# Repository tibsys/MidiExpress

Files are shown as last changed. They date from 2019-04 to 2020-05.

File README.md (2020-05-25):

# A MIDI-USB expression pedal for 25 Euros

MIDIExpress is a MIDI-PC interface originaly designed to connect an expression pedal to a **PC** or an **iPad** using USB.

## Current version

**Version 1.0**

## Licensing

The design and source codes are provided freely under a closed licence. It makes you able to implement the whole project for your own usage but not to sell it.

If you want to use it in a commercial project please contact me at tristan@alefbet.net.

## IMPORTANT: USB device PID and VID

The current values for PID and VID are random values (PID=0x2340, VID=Ox8030). They are not registered with USB-FI. You may override these values but your are not allowed to sell a product using these ID.

## Cost

_Prices include VAT 20%_

| Part | Unit (€) | Qty | Sub-total (€) |
|---|---|-----|---|
| M-AUDIO EX-P | 16.00 | 1 | 16.00 |
| ATmega 32u4 | 4.00 | 1 | 4.00 |
| USB cable (1) | 2.60 | 1 | 2.60 |
| USB connector (2) | 1.70 | 1 | 1.70 |
| Small parts | 0.50 | - | 0.50 |
|-------------------|----------|-----|---------------|
| Total | 24.80 | 1 | 24.80 |

(1): Bare USB cable
(2): USB Micro B connector

If you dont' want to do it yourself, please contact me at tristan@alefbet.net

## Requirements

- provide PC connectivity to an expression with a Jack connector
- ensure compatibility with all DAWs and MIDI controllers

## Presentation

The project consists in an electronic device which is responsible of converting the pedal into a MIDI device. 

## Licenses and credits

- Arduino schemas made with [Fritzing](http://fritzing.org/).
- Configuration software made with Qt 5.12.0 community edition.

# Do It Yourself

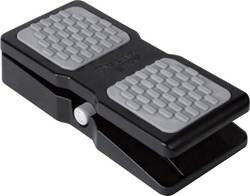
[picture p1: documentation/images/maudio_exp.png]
USB-MIDI expression pedal based on M-AUDIO EX-P


The USB-MIDI expression pedal is based on an M-AUDIO EX-P expression pedal (around 16 Euros on Amazon). The electronic device (see Jack-USB section) is embedded into the pedal and the original Jack cable is replaced with a USB cable.

This device is powered by USB.

## Architecture

> The original M-Audio EX-P pedal contains a switch for polarity inversion and a potentiometer for the sensitivity.

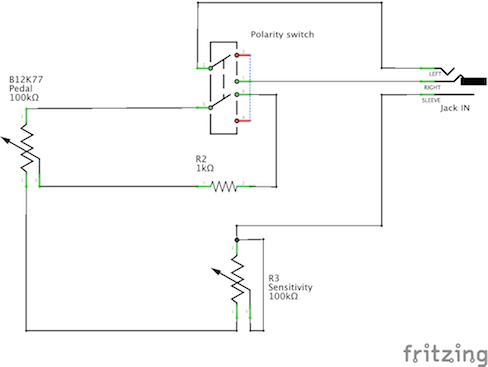
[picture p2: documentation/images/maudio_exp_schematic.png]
Original M-Audio EX-P pedal schematic


> We disabled the polarity switch and kept the sensitivity potentiometer to give manual control on the expression range.

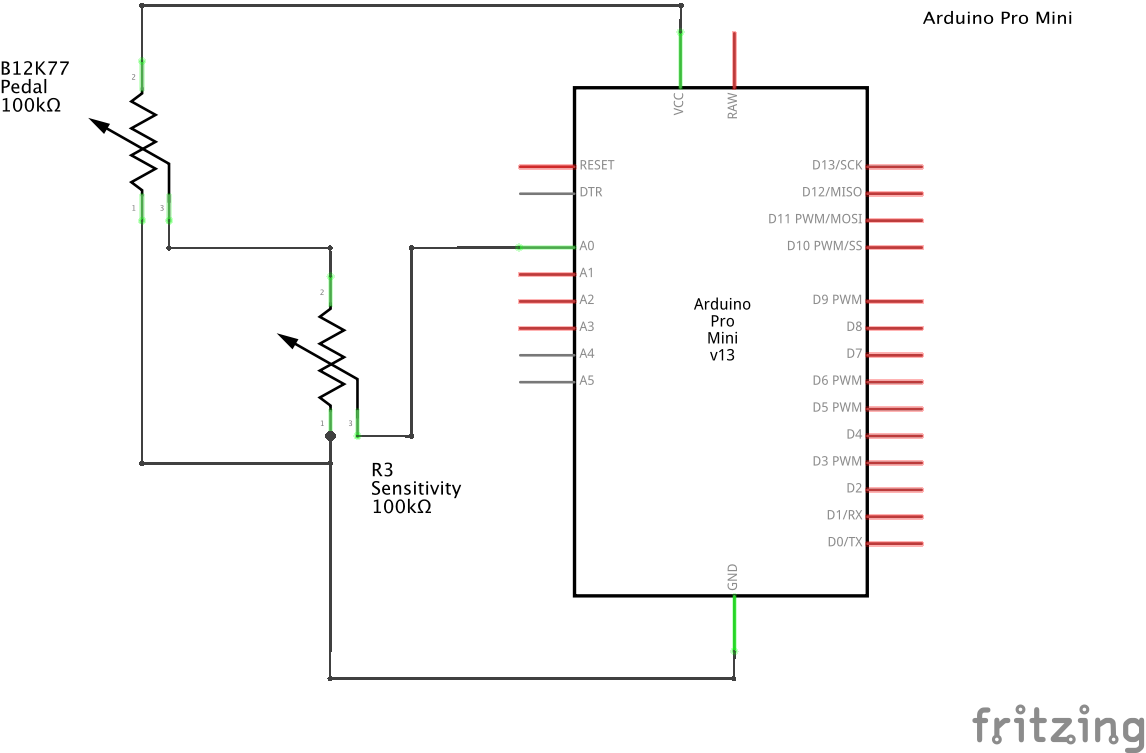
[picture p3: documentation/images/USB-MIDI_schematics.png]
Modified M-Audio EX-P pedal schematic


## Protocol

The pedal does not use any specific channel, it communicates with the *ALL* channel (1-16).

**Pedal -> DAW**

The pedal only sends *Foot Controller* Control Change (MIDI CC 4) on *ALL* channel. Values are between 0 (pedal open) and 128 (pedal closed).

**DAW -> Pedal**

All messages are ignored.

## Mounting procedure

> Before mounting the pedal you'll have to flash the Arduino program. (See Arduino folder). 

If you want the device to have a more friendly name than *Arduino Leonardo*, install the board description files into Arduino IDE (see support folder) and use the *MIDI Expression pedal* board instead of *Arduino Leonardo*.

> All the soldering should be done on the top side of the Arduino in order to be able to stick it to the bottom of the pedal.

- Open the M-AUDIO pedal by unscrewing all screws

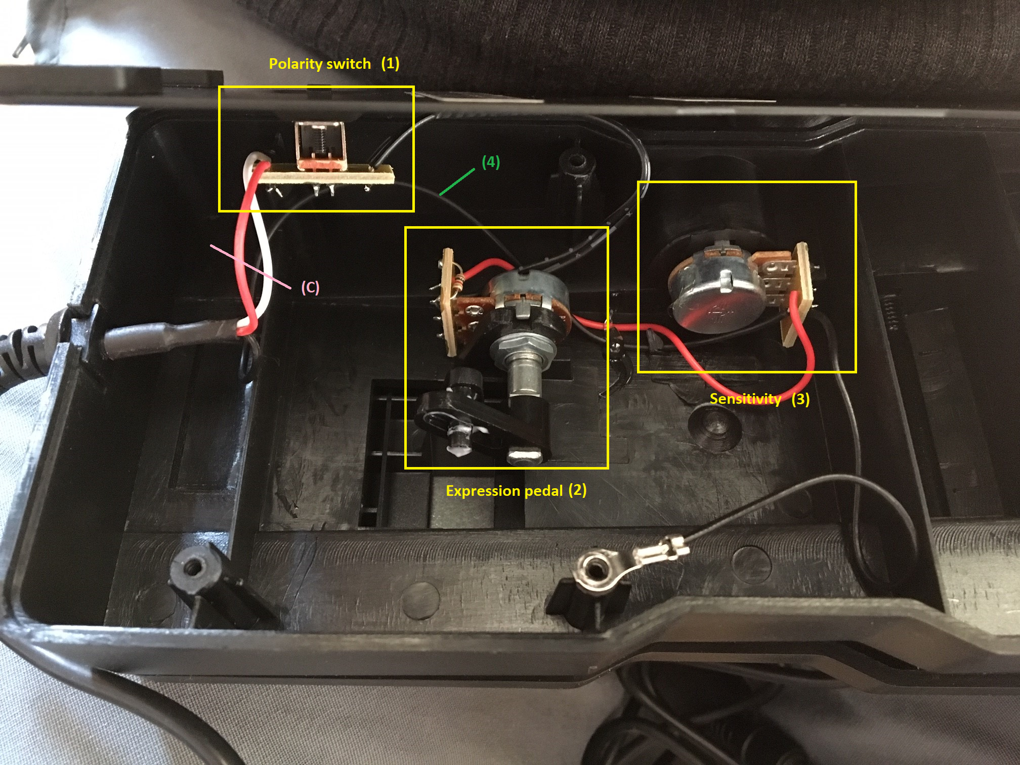
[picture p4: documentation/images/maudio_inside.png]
Inside not-modified M-AUDIO EX-P pedal


- Desolder the polarity switch wires (1)
- Cut the JACK cable and remove the grommet, we will reuse it later

Get the grommet

- Solder the black wire (4) of sensitivity potentiometer (3) to Arduino GND
- Solder the black wire (5) of expression pedal potentiometer (2) to Arduino VCC
> The wire is connected to the input of the potentiometer
- Solder the black wire (6) of expression pedal potentiometer (2) to Arduino A0 
> The wire is connected to the output of the potentiometer

- Insert the bare USB cable into the grommet and solder the Micro USB connector
- Add some black tape on the USB cable in order to fix it with the grommet (the tape sticky side on the cable, the cable will adhere to the grommet by friction)
- Insert the Micro USB connector into the Arduino USB port
- Stick the Arduino board to the bottom of the pedal with some good melted glue (and let it dry)

After sticking the Arduino

- Test the pedal with you DAW

> The pedal in high position

Pedal test

> The pedal in low position

Pedal test

- Close the M-AUDIO pedal.

- You're done

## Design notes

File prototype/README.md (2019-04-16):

# prototype

This sub-tree contains the projects created for the prototype. It will be removed at the end.

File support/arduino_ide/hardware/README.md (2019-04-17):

## Arduino board definition

Move this subdirectory "midiexpress" to the Arduino directory under hardware subdir.

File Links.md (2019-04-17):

# How to

This page gathers some helpful documentation related to AVR, MIDI and enclosures.

## MIDI how tos
- https://www.arduino.cc/en/Tutorial/MidiDevice

## Flash the firwmare into an Arduino Nano
- https://skyduino.wordpress.com/2011/12/02/tutoriel-avrdude-en-ligne-de-commande/
- https://tutorial.cytron.io/2015/02/05/using-avr-usbasp-to-program-arduino/
- http://www.hmangas.com/Electronica/Datasheets/USBasp/AVR-USBasp%20User%20Manual.pdf
- https://www.fischl.de/usbasp/
- avrdude -v -pm328p -cavrisp -b19200 -P/dev/cu.usbserial-A603UXCD -D -Uflash:w:/Users/tristan/Downloads/MidiShield1.hex
- avrdude -v -p m328p -c usbasp -e -b 19200 -U flash:w:/Users/tristan/Downloads/MidiShield1.hex
- https://tosiek.pl/usbasp-v2-0-warning-cannot-set-sck-period/
- https://github.com/obdev/v-usb
- http://ww1.microchip.com/downloads/en/DeviceDoc/ATmega48A-PA-88A-PA-168A-PA-328-P-DS-DS40002061A.pdf

## USB 
- https://codeandlife.com/2017/09/17/5-usb-midi-adapter-with-atmega32u4/
- http://liveelectronics.musinou.net/MIDIdeviceName.php
- http://pid.codes

## A étudier
- http://codeandlife.com/2017/09/17/5-usb-midi-adapter-with-atmega32u4/#more-2071

## Fasteners
- https://docs-emea.rs-online.com/webdocs/0314/0900766b803148ae.pdf

## Grommets
- https://fr.rs-online.com/web/p/passe-cables-en-caoutchouc/1879605/

## Cables and connectors
- [Bare USB-A, 5.26 Euros](https://fr.rs-online.com/web/p/cables-usb/3248362/)
- [USB-A to Mini-B, 2.60 Euros](https://www.amazon.fr/Vitesse-Broches-Alimentation-Donn%C3%A9es-Cordon/dp/B00L365PY6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)
- [Micro-B Connector, 1.38 Euros](https://fr.rs-online.com/web/p/connecteurs-micro-usb/1360889/)
- [Micro-B shield, 0.285 Euros](https://fr.rs-online.com/web/p/accessoires-de-connecteur-usb/1362300/)
- [USB-A to Mini-B, 3.60 Euros](https://fr.rs-online.com/web/p/products/1216571/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ôle_De_Process-_-Boutons-Poussoirs_And_Voyant_Lumineux_Et_Boîtes_À%C2%A0Boutons_Industriels%7CBoîtes_À%C2%A0Boutons_Équipées-_-PRODUCT_GROUP&matchtype=&pla-458695438936&gclid=EAIaIQobChMI7JeMr4jS4QIVRPhRCh3LxATJEAQYAyABEgKSVPD_BwE&gclsrc=aw.ds)
- [USB-A to Micro-B, 4.80 Euros](https://fr.rs-online.com/web/p/cables-usb/1828496/)

## AVR how tos
- https://maker.pro/custom/tutorial/how-to-take-analog-readings-with-an-avr-microcontroller

## Extra documentation
- https://www.instructables.com/id/Arduino-USB-MIDI-Interface/
- http://www.takachi-enclosure.com/data/c16-17/MX.pdf
- http://www.takachi-enclosure.com/data/c16-17/LCS.pdf
- https://fr.farnell.com/lumberg/klb-3/embase-femelle-chassis-6-35mm/dp/1217017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|pcrid|80993875142|&CAWELAID=120185620000056177&CAGPSPN=pla&CAAGID=13038046742&CMP=KNC-GFR-GEN-SHOPPING-1217017&CATCI=pla-134775292622
- http://www.takachi-enclosure.com/data/c16-17/2017vol3_21-23.pdf
- http://www.takachi-enclosure.com/data/c16-17/SU.pdf
- http://www.takachi-enclosure.com/data/c16-17/SW.pdf
- https://www.astuces-pratiques.fr/electronique/comment-brancher-un-potentiometre
- https://components101.com/sites/default/files/component_pin/potentiometer-pinout.png

## Notes
- M-Audio EX P USB cable is 1/4"
- M-Audio EX P potentiometer is 10k linear

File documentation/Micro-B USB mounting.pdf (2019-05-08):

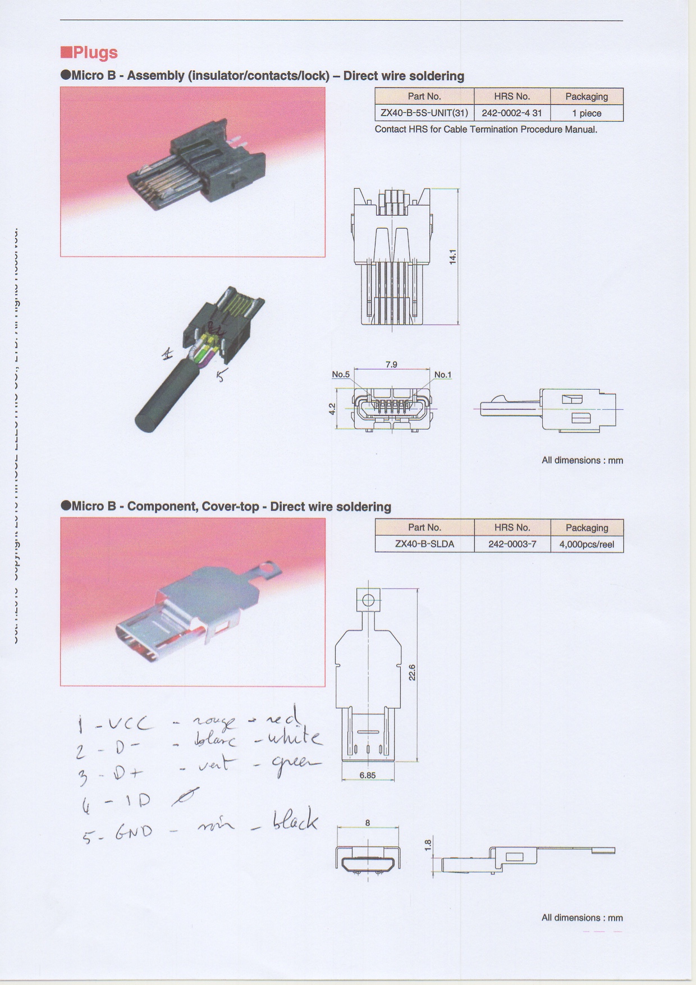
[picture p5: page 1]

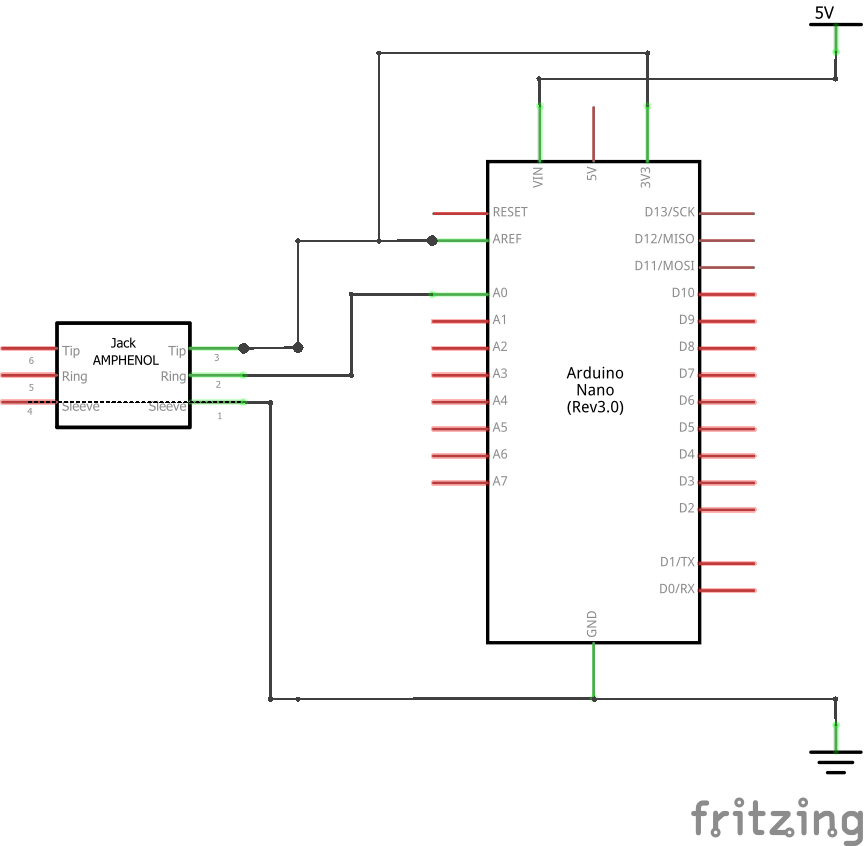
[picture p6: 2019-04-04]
documentation/images/board_schematics.png

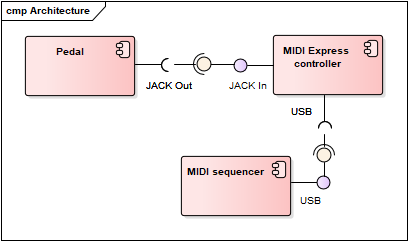
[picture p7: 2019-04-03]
documentation/images/architecture.png

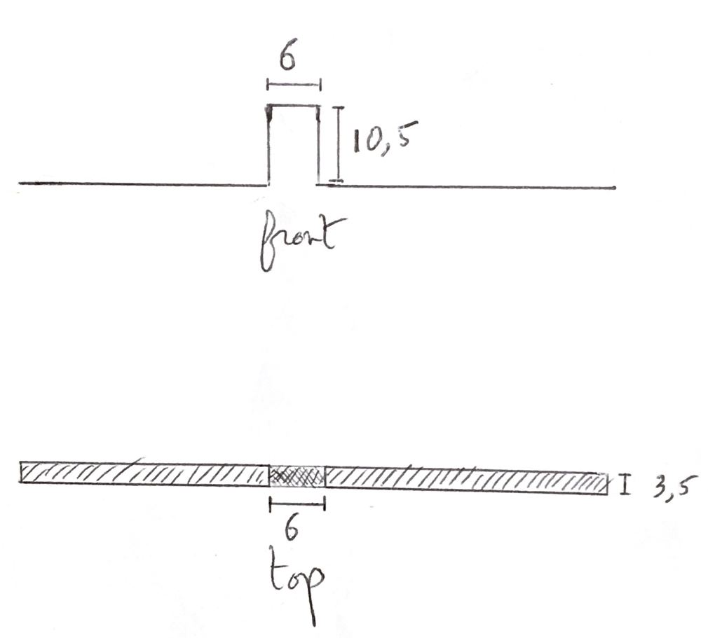
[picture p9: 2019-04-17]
documentation/images/maudio_enclosure.png

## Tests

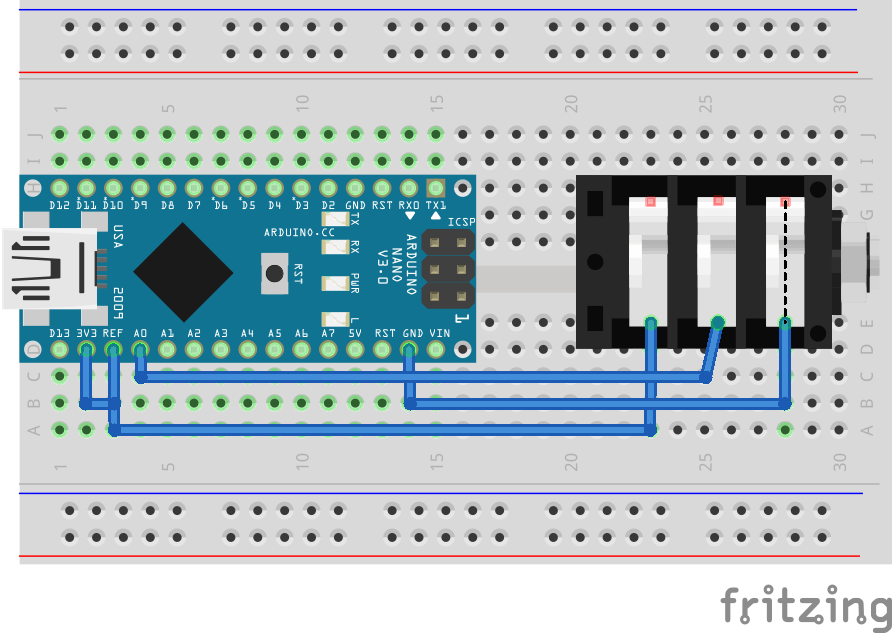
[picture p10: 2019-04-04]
documentation/images/test_board.png

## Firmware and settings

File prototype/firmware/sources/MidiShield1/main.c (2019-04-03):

/* Name: main.c
 * MIDI CONVERTER
 *
 * MOCO: Midi Output Converter
 * MICO: Midi Input Converter
 *
 * (C) 2010 by morecat_lab
 */



#include <string.h>
#include <avr/io.h>
#include <avr/interrupt.h>
#include <avr/pgmspace.h>
#include <avr/wdt.h>

#include "usbdrv/usbdrv.h"
#include "usbdrv/oddebug.h"

extern void parseUSBMidiMessage(uchar *, uchar);
extern uchar parseSerialMidiMessage(uchar);

#define setPortBit0(port, bit) *(port) &= ~_BV(bit);
#define setPortBit1(port, bit) *(port) |= _BV(bit);
#define flipPortBit(port, bit) (*(port) ^= _BV(bit))
#define setPortBit(port, bit, val) { \
    if ((val) == 0) { setPortBit0((port), (bit)); } else	\
      { setPortBit1((port), (bit)); }				\
}

/* debugging LED */
#ifdef ARDUINO
#define LED_OFF  { PORTB &= ~0x20; }
#define LED_ON   { PORTB |=  0x20; }
#define FLIP_LED { PORTB ^=  0x20; }
#else
#define LED_OFF  { PORTB &= ~0x01; }
#define LED_ON   { PORTB |=  0x01; }
#define FLIP_LED { PORTB ^=  0x01; }
#endif

#define RECEIVER
#define TRANSMITTER

/*
 PORT ASSIGN
 PD0: RxD (Serial MIDI)
 PD1: TxD (Serial MIDI)
 PD2: USB D+
 PD3: USB D-

 PD5: LED Monitor

 */

#define HW_CDC_BULK_OUT_SIZE     8
#define HW_CDC_BULK_IN_SIZE      8

#define	TRUE			1
#define	FALSE			0

enum {
    SEND_ENCAPSULATED_COMMAND = 0,
    GET_ENCAPSULATED_RESPONSE,
    SET_COMM_FEATURE,
    GET_COMM_FEATURE,
    CLEAR_COMM_FEATURE,
    SET_LINE_CODING = 0x20,
    GET_LINE_CODING,
    SET_CONTROL_LINE_STATE,
    SEND_BREAK
};

// This deviceDescrMIDI[] is based on 
// http://www.usb.org/developers/devclass_docs/midi10.pdf
// Appendix B. Example: Simple MIDI Adapter (Informative)

// B.1 Device Descriptor
static PROGMEM char deviceDescrMIDI[] = {	/* USB device descriptor */
  18,			/* sizeof(usbDescriptorDevice): length of descriptor in bytes */
  USBDESCR_DEVICE,	/* descriptor type */
  0x10, 0x01,		/* USB version supported */
  0,			/* device class: defined at interface level */
  0,			/* subclass */
  0,			/* protocol */
  8,			/* max packet size */
  USB_CFG_VENDOR_ID,	/* 2 bytes */
  USB_CFG_DEVICE_ID,	/* 2 bytes */
  USB_CFG_DEVICE_VERSION,	/* 2 bytes */
  1,			/* manufacturer string index */
  2,			/* product string index */
  0,			/* serial number string index */
  1,			/* number of configurations */
};

// B.2 Configuration Descriptor
static PROGMEM char configDescrMIDI[] = { /* USB configuration descriptor */
  9,	   /* sizeof(usbDescrConfig): length of descriptor in bytes */
  USBDESCR_CONFIG,		/* descriptor type */
  101, 0,			/* total length of data returned (including inlined descriptors) */
  2,		      /* number of interfaces in this configuration */
  1,				/* index of this configuration */
  0,				/* configuration name string index */
#if USB_CFG_IS_SELF_POWERED
    (1 << 7) | USBATTR_SELFPOWER,       /* attributes */
#else
    (1 << 7),                           /* attributes */
#endif
  USB_CFG_MAX_BUS_POWER / 2,	/* max USB current in 2mA units */

// B.3 AudioControl Interface Descriptors
// The AudioControl interface describes the device structure (audio function topology) 
// and is used to manipulate the Audio Controls. This device has no audio function 
// incorporated. However, the AudioControl interface is mandatory and therefore both 
// the standard AC interface descriptor and the classspecific AC interface descriptor 
// must be present. The class-specific AC interface descriptor only contains the header 
// descriptor.

// B.3.1 Standard AC Interface Descriptor
// The AudioControl interface has no dedicated endpoints associated with it. It uses the 
// default pipe (endpoint 0) for all communication purposes. Class-specific AudioControl 
// Requests are sent using the default pipe. There is no Status Interrupt endpoint provided.
  /* descriptor follows inline: */
  9,			/* sizeof(usbDescrInterface): length of descriptor in bytes */
  USBDESCR_INTERFACE,	/* descriptor type */
  0,			/* index of this interface */
  0,			/* alternate setting for this interface */
  0,			/* endpoints excl 0: number of endpoint descriptors to follow */
  1,			/* */
  1,			/* */
  0,			/* */
  0,			/* string index for interface */

// B.3.2 Class-specific AC Interface Descriptor
// The Class-specific AC interface descriptor is always headed by a Header descriptor 
// that contains general information about the AudioControl interface. It contains all 
// the pointers needed to describe the Audio Interface Collection, associated with the 
// described audio function. Only the Header descriptor is present in this device 
// because it does not contain any audio functionality as such.
  /* descriptor follows inline: */
  9,			/* sizeof(usbDescrCDC_HeaderFn): length of descriptor in bytes */
  36,			/* descriptor type */
  1,			/* header functional descriptor */
  0x0, 0x01,		/* bcdADC */
  9, 0,			/* wTotalLength */
  1,			/* */
  1,			/* */

// B.4 MIDIStreaming Interface Descriptors

// B.4.1 Standard MS Interface Descriptor
  /* descriptor follows inline: */
  9,			/* length of descriptor in bytes */
  USBDESCR_INTERFACE,	/* descriptor type */
  1,			/* index of this interface */
  0,			/* alternate setting for this interface */
  2,			/* endpoints excl 0: number of endpoint descriptors to follow */
  1,			/* AUDIO */
  3,			/* MS */
  0,			/* unused */
  0,			/* string index for interface */

// B.4.2 Class-specific MS Interface Descriptor
  /* descriptor follows inline: */
  7,			/* length of descriptor in bytes */
  36,			/* descriptor type */
  1,			/* header functional descriptor */
  0x0, 0x01,		/* bcdADC */
  65, 0,			/* wTotalLength */

// B.4.3 MIDI IN Jack Descriptor
  /* descriptor follows inline: */
  6,			/* bLength */
  36,			/* descriptor type */
  2,			/* MIDI_IN_JACK desc subtype */
  1,			/* EMBEDDED bJackType */
  1,			/* bJackID */
  0,			/* iJack */

  /* descriptor follows inline: */
  6,			/* bLength */
  36,			/* descriptor type */
  2,			/* MIDI_IN_JACK desc subtype */
  2,			/* EXTERNAL bJackType */
  2,			/* bJackID */
  0,			/* iJack */

//B.4.4 MIDI OUT Jack Descriptor
  /* descriptor follows inline: */
  9,			/* length of descriptor in bytes */
  36,			/* descriptor type */
  3,			/* MIDI_OUT_JACK descriptor */
  1,			/* EMBEDDED bJackType */
  3,			/* bJackID */
  1,			/* No of input pins */
  2,			/* BaSourceID */
  1,			/* BaSourcePin */
  0,			/* iJack */

  /* descriptor follows inline: */
  9,			/* bLength of descriptor in bytes */
  36,			/* bDescriptorType */
  3,			/* MIDI_OUT_JACK bDescriptorSubtype */
  2,			/* EXTERNAL bJackType */
  4,			/* bJackID */
  1,			/* bNrInputPins */
  1,			/* baSourceID (0) */
  1,			/* baSourcePin (0) */
  0,			/* iJack */


// B.5 Bulk OUT Endpoint Descriptors

//B.5.1 Standard Bulk OUT Endpoint Descriptor
  /* descriptor follows inline: */
  9,			/* bLenght */
  USBDESCR_ENDPOINT,	/* bDescriptorType = endpoint */
  0x1,			/* bEndpointAddress OUT endpoint number 1 */
  3,			/* bmAttributes: 2:Bulk, 3:Interrupt endpoint */
  8, 0,			/* wMaxPacketSize */
  10,			/* bIntervall in ms */
  0,			/* bRefresh */
  0,			/* bSyncAddress */

// B.5.2 Class-specific MS Bulk OUT Endpoint Descriptor
  /* descriptor follows inline: */
  5,			/* bLength of descriptor in bytes */
  37,			/* bDescriptorType */
  1,			/* bDescriptorSubtype */
  1,			/* bNumEmbMIDIJack  */
  1,			/* baAssocJackID (0) */


//B.6 Bulk IN Endpoint Descriptors

//B.6.1 Standard Bulk IN Endpoint Descriptor
  /* descriptor follows inline: */
  9,			/* bLenght */
  USBDESCR_ENDPOINT,	/* bDescriptorType = endpoint */
  0x81,			/* bEndpointAddress IN endpoint number 1 */
  3,			/* bmAttributes: 2: Bulk, 3: Interrupt endpoint */
  8, 0,			/* wMaxPacketSize */
  10,			/* bIntervall in ms */
  0,			/* bRefresh */
  0,			/* bSyncAddress */

// B.6.2 Class-specific MS Bulk IN Endpoint Descriptor
  /* descriptor follows inline: */
  5,			/* bLength of descriptor in bytes */
  37,			/* bDescriptorType */
  1,			/* bDescriptorSubtype */
  1,			/* bNumEmbMIDIJack (0) */
  3,			/* baAssocJackID (0) */
};


uchar usbFunctionDescriptor(usbRequest_t * rq) {
  if (rq->wValue.bytes[1] == USBDESCR_DEVICE) {
    usbMsgPtr = (uchar *) deviceDescrMIDI;
    return sizeof(deviceDescrMIDI);
  } else {		/* must be config descriptor */
    usbMsgPtr = (uchar *) configDescrMIDI;
    return sizeof(configDescrMIDI);
  }
}

/* ------------------------------------------------------------------------- */
/* ----------------------------- USB interface ----------------------------- */
/* ------------------------------------------------------------------------- */

static uchar    sendEmptyFrame;
// static uchar    modeBuffer[7];

uchar usbFunctionSetup(uchar data[8]) {
  usbRequest_t    *rq = (void *)data;

  if((rq->bmRequestType & USBRQ_TYPE_MASK) == USBRQ_TYPE_CLASS){    /* class request type */
    
    /*  Prepare bulk-in endpoint to respond to early termination   */
    if ((rq->bmRequestType & USBRQ_DIR_MASK) ==
	USBRQ_DIR_HOST_TO_DEVICE)
      sendEmptyFrame = 1;
  }
  return 0xff;
}

/*---------------------------------------------------------------------------*/
/* usbFunctionRead                                                           */
/*---------------------------------------------------------------------------*/

uchar usbFunctionRead( uchar *data, uchar len ) {
	data[0] = 0;
	data[1] = 0;
	data[2] = 0;
	data[3] = 0;
	data[4] = 0;
	data[5] = 0;
	data[6] = 0;
    return 7;
}

/*---------------------------------------------------------------------------*/
/* usbFunctionWrite                                                          */
/*---------------------------------------------------------------------------*/

uchar usbFunctionWrite(uchar * data, uchar len) {
  // setPortBit1(&PORTD, 5);		// DEBUG LED
  /* parseMidiMessage(data, len); */
  return 1;
}
/*---------------------------------------------------------------------------*/
/* usbFunctionWriteOut                                                       */
/*                                                                           */
/* this Function is called if a MIDI Out message (from PC) arrives.          */
/*                                                                           */
/*---------------------------------------------------------------------------*/

#ifdef RECEIVER
#define    RX_SIZE        (HW_CDC_BULK_IN_SIZE)
static uchar utxrdy = FALSE;	/* USB Packet ready in utx_buf */
static uchar rx_buf[RX_SIZE];	/* tempory buffer */
static uchar utx_buf[RX_SIZE];	/* BULK_IN buffer */
#endif

#ifdef TRANSMITTER
#define    TX_SIZE        (HW_CDC_BULK_OUT_SIZE<<2)
#define    TX_MASK        (TX_SIZE-1)
static uchar uwptr = 0, irptr = 0;
static uchar tx_buf[TX_SIZE];
#endif

void usbFunctionWriteOut(uchar *data, uchar len ) {
#ifdef TRANSMITTER
  parseUSBMidiMessage(data, len);
#endif
}

#ifdef TRANSMITTER
void parseUSBMidiMessage(uchar *data, uchar len) {
  uchar cin = (*data) & 0x0f;	/* CABLE NOを無視する */
  uchar i;

#ifdef DEBUG
  if (cin == 8) {
    LED_OFF;
  } else if (cin == 9) {
    if (((*(data+3)) & 0x7f) == 0) {
      LED_OFF;
    } else {
      LED_ON;
    }
  }
#else
  FLIP_LED;
#endif

  if (cin > 1) {		/* ignore cin == 0 and cin == 1 */
    for (i = 1 ; i < 4 ; i++) {
      tx_buf[uwptr++] = *(data + i);
      uwptr &= TX_MASK;
      if (i == 1) {
	if ((cin == 5) || /* single byte system common */
	    (cin == 15))  /* single byte */
	  break;
      }
      if (i == 2) {
	if ((cin == 2) ||  /* two-byte system common */
	    (cin == 6) ||  /* system ex end with 2 bytes */
	    (cin == 12) || /* program change */
	    (cin == 13))   /* channel pressure */
	  break;
      }
    }
  }

  if (len > 4) {
    parseUSBMidiMessage(data+4, len-4);
  }
}
#endif

#ifdef RECEIVER

uchar parseSerialMidiMessage(uchar RxByte) {
  static uchar PC = 0;
  static uchar SysEx = FALSE;
  static uchar stateTransTable[] = {
    0, 				/* 0 dummy */
    0,				/* 1 dummy */
    3,				/* 2->3 NOTE OFF (3) */
    2 | 0x80,			/* 3->2 */
    5,				/* 4->5 NOTE ON (3) */
    4 | 0x80,			/* 5->4 */
    7,				/* 6->7 Polyphonic key pressure (3) */
    6 | 0x80,			/* 7->6 */
    9,				/* 8->9 Control Change (3) */
    8 | 0x80,			/* 8->9 */
    10 | 0x80,			/* 10->10 program change (2) */
    0,				/* dummy */
    12 | 0x80,			/* 12->12 Channel Pressure (2) */
    0,				/* 13 dummy */
    15,				/* 14->15 Pitch Bend (3) */
    14 | 0x80			/* 15->14 */
  };

  FLIP_LED;	// DEBUG LED
  if(SysEx){  /* MIDI System Message */
    if(RxByte == 0xf7){		/* MIDI_EndSysEx */
      SysEx = FALSE;
    }
    return FALSE;
  }
  if (RxByte >= 0xF8){		/* Single Byte Message */
    utx_buf[0] = 0x0f;
    utx_buf[1] = RxByte;
    utx_buf[2] = 0;
    utx_buf[3] = 0;
    return TRUE;
  }

  if(RxByte > 0x7F){		/* Channel message */
    if(RxByte == 0xf0){		/* MIDI_StartSysEx */
      SysEx = TRUE;
      return FALSE;
    }
    PC = 0;
  }

  if (PC == 0) {
    PC = (((RxByte >> 4) & 0x07) + 1) * 2;
    // conversion
    // 0x80 -> 2, 0x90 -> 4, 0xa0 -> 6, 0xb0 -> 8, 0xc0 -> 10, 0xd0 -> 12, 0xe0 -> 14
    rx_buf[0] = RxByte >> 4;
    rx_buf[1] = RxByte;
    rx_buf[3] = 0;
  } else {
    uchar tt = stateTransTable[PC];
    rx_buf[(PC & 1) + 2] = RxByte;
    PC = tt & 0x0f;
    if ((tt & 0x80) != 0) {
      memcpy(utx_buf, rx_buf, 4);
      return TRUE;
    }
  }
  return FALSE;
}

#endif

#ifdef ARDUINO
#define PORTD_DDR (0x00)
#else
#define PORTD_DDR (0b00100010)
#endif

static void hardwareInit(void) {
  uchar i, j;

  /* activate pull-ups except on USB lines */
  USB_CFG_IOPORT =
    (uchar) ~ ((1 << USB_CFG_DMINUS_BIT) |
	       (1 << USB_CFG_DPLUS_BIT) | PORTD_DDR) ;
  /* all pins input except USB (-> USB reset) */
#ifdef USB_CFG_PULLUP_IOPORT
  /* use usbDeviceConnect()/usbDeviceDisconnect() if available */
  USBDDR = 0 | PORTD_DDR;	/* we do RESET by deactivating pullup */
  usbDeviceDisconnect();
#else
  USBDDR = (1 << USB_CFG_DMINUS_BIT) | (1 << USB_CFG_DPLUS_BIT) | PORTD_DDR ;
  /* for output (LED, TxD) */
#endif

  j = 0;
  while (--j) {		/* USB Reset by device only required on Watchdog Reset */
    i = 0;
    while (--i);	/* delay >10ms for USB reset */
  }
#ifdef USB_CFG_PULLUP_IOPORT
  usbDeviceConnect();
#else
  USBDDR = 0 | PORTD_DDR;		/*  remove USB reset condition */
#endif

  /* set baud rate */
  UBRRL	= 31;			/* 312500Hz at 16MHz clock */
  /*  */
  UCSRB	= (1<<RXEN) | (1<<TXEN);

  /* DEBUGGING LED */

#ifdef ARDUINO
  DDRB = 0x20;
#else
  DDRB = 0x01;
#endif
  PORTB = 0;
}

int main(void) {
  /* I activate the WDT */
  wdt_enable(WDTO_1S);
  odDebugInit();
  hardwareInit();
  usbInit();
  
  sendEmptyFrame = 0;

  sei();
  PORTB = 1;
  for(;;){
    wdt_reset();
    usbPoll();
#ifdef TRANSMITTER
    /*    send to Serial MIDI line    */
    if( (UCSRA & (1<<UDRE)) && uwptr!=irptr ) {
      UDR = tx_buf[irptr++];
      irptr &= TX_MASK;
    }
#if USB_CFG_HAVE_FLOWCONTROL == 1
    if( usbAllRequestsAreDisabled() &&
	((uwptr-irptr)&TX_MASK)<(TX_SIZE-HW_CDC_BULK_OUT_SIZE) ) {
      usbEnableAllRequests();
    }
#endif
#endif

#ifdef RECEIVER
    /*    receive from Serial MIDI line    */
    if( UCSRA & (1<<RXC)) {
      utxrdy |= parseSerialMidiMessage(UDR);
    }
    /* send packets to USB MIDI  */
    if( usbInterruptIsReady() && utxrdy ) {
      usbSetInterrupt(utx_buf, 4);
      utxrdy = FALSE;
    }
#endif
  }
}

/* EOF */

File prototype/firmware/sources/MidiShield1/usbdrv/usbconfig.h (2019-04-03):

/* Name: usbconfig.h
 * Project: AVR USB driver
 * Author: Christian Starkjohann
 * Creation Date: 2007-06-23
 * Tabsize: 4
 * Copyright: (c) 2007 by OBJECTIVE DEVELOPMENT Software GmbH
 * License: GNU GPL v2 (see License.txt) or proprietary (CommercialLicense.txt)
 * This Revision: $Id: usbconfig.h 537 2008-02-28 21:13:01Z cs $
 */

#ifndef __usbconfig_h_included__
#define __usbconfig_h_included__

#define F_CPU 16000000

/* ---------------------------- Hardware Config ---------------------------- */

#define USB_CFG_IOPORTNAME      D
/* This is the port where the USB bus is connected. When you configure it to
 * "B", the registers PORTB, PINB and DDRB will be used.
 */
#define USB_CFG_DMINUS_BIT      3
/* This is the bit number in USB_CFG_IOPORT where the USB D- line is connected.
 * This may be any bit in the port.
 */
#define USB_CFG_DPLUS_BIT       2
/* This is the bit number in USB_CFG_IOPORT where the USB D+ line is connected.
 * This may be any bit in the port. Please note that D+ must also be connected
 * to interrupt pin INT0!
 */
#define USB_CFG_CLOCK_KHZ       (F_CPU/1000)
/* Clock rate of the AVR in MHz. Legal values are 12000, 16000 or 16500.
 * The 16.5 MHz version of the code requires no crystal, it tolerates +/- 1%
 * deviation from the nominal frequency. All other rates require a precision
 * of 2000 ppm and thus a crystal!
 * Default if not specified: 12 MHz
 */

/* ----------------------- Optional Hardware Config ------------------------ */

#define USB_CFG_PULLUP_IOPORTNAME   D 
/* If you connect the 1.5k pullup resistor from D- to a port pin instead of
 * V+, you can connect and disconnect the device from firmware by calling
 * the macros usbDeviceConnect() and usbDeviceDisconnect() (see usbdrv.h).
 * This constant defines the port on which the pullup resistor is connected.
 */
#define USB_CFG_PULLUP_BIT          4 
/* This constant defines the bit number in USB_CFG_PULLUP_IOPORT (defined
 * above) where the 1.5k pullup resistor is connected. See description
 * above for details.
 */

/* --------------------------- Functional Range ---------------------------- */

#define USB_CFG_HAVE_INTRIN_ENDPOINT    1
/* Define this to 1 if you want to compile a version with two endpoints: The
 * default control endpoint 0 and an interrupt-in endpoint 1.
 */
#define USB_CFG_HAVE_INTRIN_ENDPOINT3   0
/* Define this to 1 if you want to compile a version with three endpoints: The
 * default control endpoint 0, an interrupt-in endpoint 1 and an interrupt-in
 * endpoint 3. You must also enable endpoint 1 above.
 */
#define USB_CFG_IMPLEMENT_HALT          1
/* Define this to 1 if you also want to implement the ENDPOINT_HALT feature
 * for endpoint 1 (interrupt endpoint). Although you may not need this feature,
 * it is required by the standard. We have made it a config option because it
 * bloats the code considerably.
 */
#define USB_CFG_INTR_POLL_INTERVAL      10
/* If you compile a version with endpoint 1 (interrupt-in), this is the poll
 * interval. The value is in milliseconds and must not be less than 10 ms for
 * low speed devices.
 */
#define USB_CFG_IS_SELF_POWERED         0
/* Define this to 1 if the device has its own power supply. Set it to 0 if the
 * device is powered from the USB bus.
 */
#define USB_CFG_MAX_BUS_POWER           100
/* Set this variable to the maximum USB bus power consumption of your device.
 * The value is in milliamperes. [It will be divided by two since USB
 * communicates power requirements in units of 2 mA.]
 */
/* #define USB_CFG_SAMPLE_EXACT            0 */
/* This variable affects Sampling Jitter for USB receiving. When it is 0, the
 * driver guarantees a sampling window of 1/2 bit. The USB spec requires
 * that the receiver has at most 1/4 bit sampling window. The 1/2 bit window
 * should still work reliably enough because we work at low speed. If you want
 * to meet the spec, set this value to 1. This will unroll a loop which
 * results in bigger code size.
 * If you have problems with long cables, try setting this value to 1.
 */
#define USB_CFG_IMPLEMENT_FN_WRITE      1
/* Set this to 1 if you want usbFunctionWrite() to be called for control-out
 * transfers. Set it to 0 if you don't need it and want to save a couple of
 * bytes.
 */
#define USB_CFG_IMPLEMENT_FN_READ       1
/* Set this to 1 if you need to send control replies which are generated
 * "on the fly" when usbFunctionRead() is called. If you only want to send
 * data from a static buffer, set it to 0 and return the data from
 * usbFunctionSetup(). This saves a couple of bytes.
 */
#define USB_CFG_IMPLEMENT_FN_WRITEOUT   1
/* Define this to 1 if you want to use interrupt-out (or bulk out) endpoint 1.
 * You must implement the function usbFunctionWriteOut() which receives all
 * interrupt/bulk data sent to endpoint 1.
 */
#define USB_CFG_HAVE_FLOWCONTROL        0
/* Define this to 1 if you want flowcontrol over USB data. See the definition
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

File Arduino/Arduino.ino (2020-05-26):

/*
   This program manages the USB expression pedal.

   Dependencies:
   - MIDIUSB library. To install it, use the library manager in Arduino IDE.

   The hardware is based on
   - M-AUDIO EX-P expression pedal
   - Arduino Pro Micro board

   The pedal is based on a voltage divider. We send the current VCC (+5V) in the pedal
   circuit and mesure it on the A1 analog PIN.
   Depending on the pedal position, the current measured on A1 is between 2.5V (pedal down) and 5V (pedal up).
   The position is translated to a value between 0 and 127 using the MIDI CC 4.

   Created: 2019-04-17
   Version: 1.1
   Author: Tristan Israël <tristan.israel@tibsys.com>
   
   https://www.tibsys.com/
*/

#include <MIDIUSB.h>

/**
 * Constants
 */
const bool DEBUG = false;
const int PEDAL_POSITION_INPUT = A1;  //A1 input
const int PEDAL_MAX_CURRENT = 1023; //Maximum value read on the input pin
const int PEDAL_MIN_CURRENT = 0; //Minimum value read on the input pin
const uint8_t PEDAL_MAX_MIDI = 127; //Maximum value in MIDI CC
const uint8_t PEDAL_MIN_MIDI = 0; //Minimum value in MIDI CC
const uint8_t MIDI_CC_FOOTCONTROLLER = 4; //Value for Foot Controller Control Change message

/** 
 * Variables
 */
uint8_t currentPedalPosition = 0;

void setup() {
  if(DEBUG) {
    Serial.begin(115200);
    Serial.println("MIDI Expression pedal initialized and ready!");
  }
}

void loop() {
  //Read the current position of the pedal
  uint8_t pedalPosition = readPosition();

  //If position changed, send the new value to the MIDI controller
  if(pedalPosition != currentPedalPosition) {
    sendPedalPosition(pedalPosition);
    currentPedalPosition = pedalPosition;    

    if(DEBUG) {
      Serial.print("Current pedal position=");
      Serial.println(currentPedalPosition);
    }
  }   
}

/**
 * Sends the pedal position to the MIDI controller
 */
void sendPedalPosition(uint8_t position) {
  sendControlChange(MIDI_CC_FOOTCONTROLLER, position);
}

/**
 * Sends a control change message to the MIDI controller
 * control - the CC message identifier (0-127)
 * value - the value associated to the message (0-127)
 */
void sendControlChange(byte control, byte value) {
  midiEventPacket_t event = {0xB, 0xB0, control, value};
  MidiUSB.sendMIDI(event);
  MidiUSB.flush();
}

/**
 * Reads the position of the pedal in the MIDI expression range (0-127).
 *
 * Because the pedal is a voltage divider, the value measured is between 512 and 1023.
 * The lowest value (512) is converted into the MIDI value 0.
 * The highest value (1023) is converted into the MIDI value 127.
 * The values in the range [512-1023] are converted into MIDI values in the range [0-127].
 */
uint8_t readPosition()
{
  int val = analogRead(PEDAL_POSITION_INPUT);
  /*Serial.print("val=");
  Serial.println(val);*/
  return (uint8_t) (map(val, PEDAL_MIN_CURRENT, PEDAL_MAX_CURRENT, PEDAL_MIN_MIDI, PEDAL_MAX_MIDI));  
  //Serial.print("pedal position:");
  //Serial.println(pedalPosition);
}

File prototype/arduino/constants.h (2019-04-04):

//
// Constants definitions
//
const uint8_t INPUT_PIN = A0;

const uint8_t MIDI_CMD_CONTROL = 0xB1;
const uint8_t MIDI_CMD_VOLUME = 7;
const uint8_t MIDI_CMD_EXPRESSION = 11;
const uint16_t MIDI_TRANSFER_RATE = 31250;
const uint8_t MIDI_MAX_EXPRESSION = 127;
const uint8_t MIDI_MAX_VOLUME = 254;

const uint8_t MEMORY_INIT_MAGIC = 0xFA;
enum MemorySlot {
  MEMORY_SLOT_INIT = 0,
  MEMORY_SLOT_PEDALTYPE = 1
};

enum PedalType {
  PEDAL_TYPE_VOLUME = 1,
  PEDAL_TYPE_EXPRESSION = 2,
};

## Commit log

2019-04-03 Started the development of the Arduino module
2019-04-04 Create Fritzing board
    [Board.fzz]
2019-04-04 Added costs estimation
    [Board.fzz]
2019-04-04 Progressed on the Arduino software
2019-04-15 Changed design and added some documentation. Started coding of the firmware (USB-MIDI pedal)
    [MAUDIO EX-P.fzz, USB-MIDI.fzz]
2019-04-17 Refactored documentation. Coded version 1.0 of USB-MIDI expression pedal Arduino program. Removed AVR firmware tests.
2019-04-17 Added documentation and finalized the Arduino program
2019-05-08 Create Micro-B USB mounting.pdf
2020-05-26 Update Arduino.ino
    Added flush for midi messages for more accuracy

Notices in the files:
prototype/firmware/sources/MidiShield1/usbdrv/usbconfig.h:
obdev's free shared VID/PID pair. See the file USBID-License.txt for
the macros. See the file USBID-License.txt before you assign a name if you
